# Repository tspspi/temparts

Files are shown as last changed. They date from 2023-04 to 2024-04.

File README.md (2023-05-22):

# Various parts for transmission electron microscopy

## Sampleholder template for the FEI TECNAI F20/G20

## Mirror sample tip for coherent photon measurement on the FEI TECNAI F20/G20

## Mirrors for coherent photon measurement on the FEI TECNAI F20/G20

## For simulation: Template of the Octagon of the FEI TECNAI F20/G20

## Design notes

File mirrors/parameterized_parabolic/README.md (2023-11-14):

# Parameterizable parabolic mirror

## Base mirror: ```parabolic_base```

This is a simple parameterizable parabolic mirror.

| | |
| --- | --- |
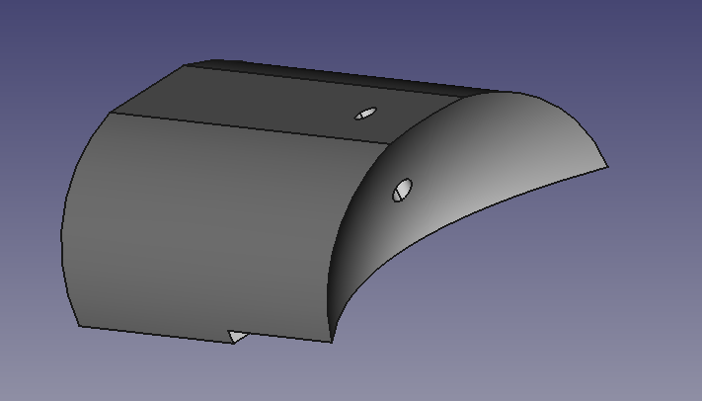
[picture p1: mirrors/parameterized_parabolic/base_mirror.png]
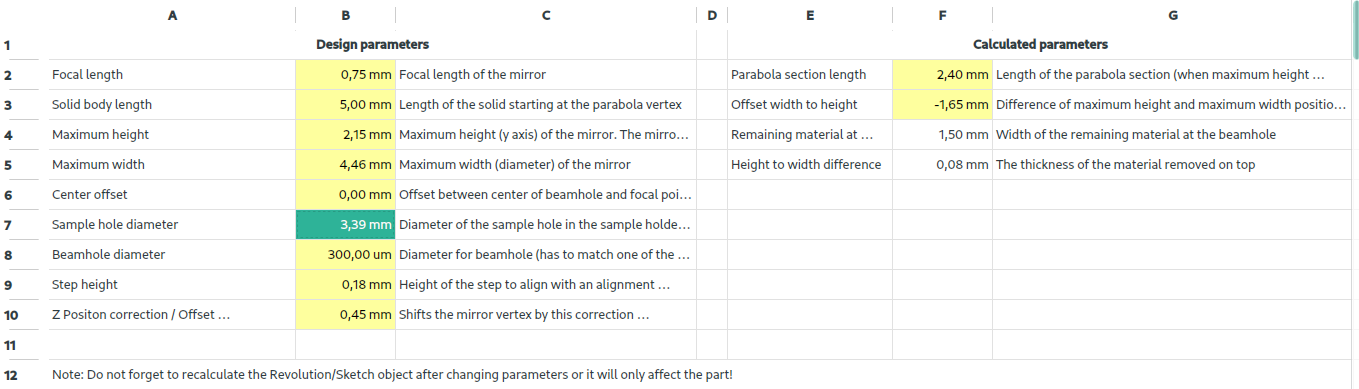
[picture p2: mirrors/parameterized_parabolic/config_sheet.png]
|  |  |

## Mirror with screw mount: ```parabolic_screwmount```

The same mirror model (using the same configuration) with a simple screw
mount

| | |
| --- | --- |
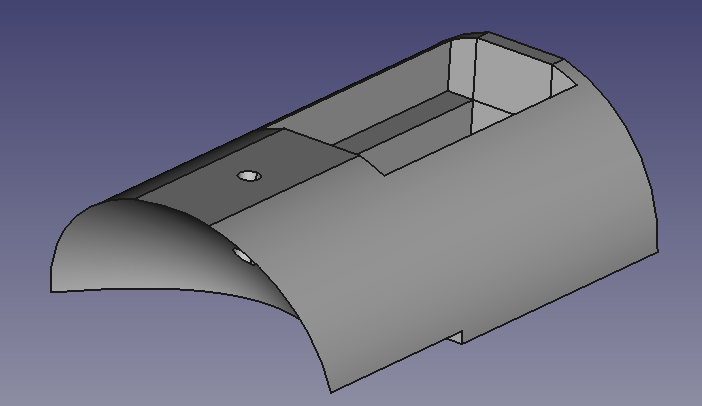
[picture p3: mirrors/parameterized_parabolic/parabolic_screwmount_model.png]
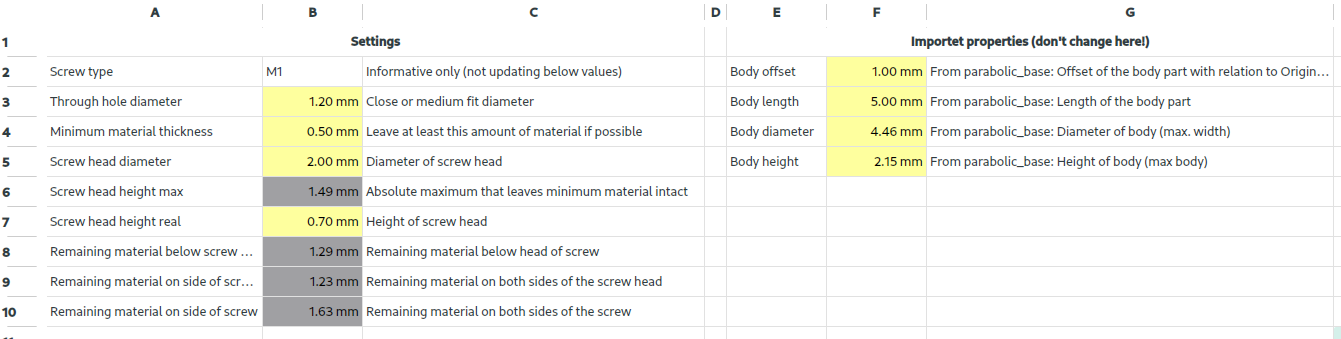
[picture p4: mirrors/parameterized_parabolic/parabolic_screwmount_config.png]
|  |  |

## Simulation with screw mount

There is a (currently incomplete - not including the sample holder) parameterized
simulation that pulls design parameters from the other models for the screw mounted
parabolic mirror in ```parabolic_simulation```

| | |
| --- | --- |
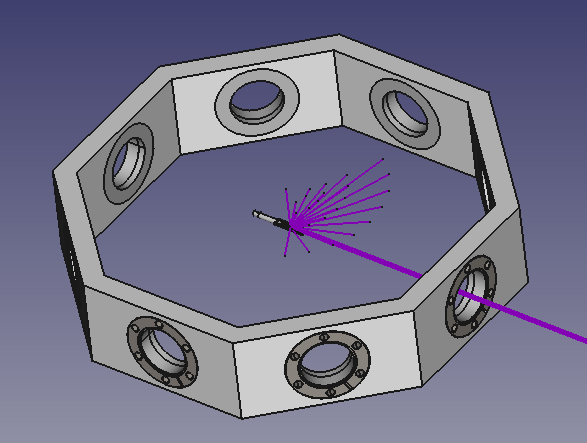
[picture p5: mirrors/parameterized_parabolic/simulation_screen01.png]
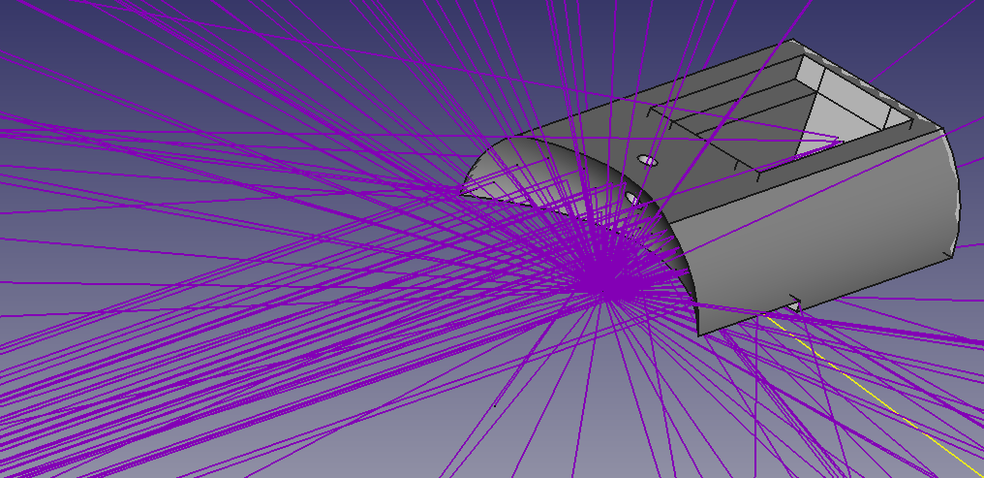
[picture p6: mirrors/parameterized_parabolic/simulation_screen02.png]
|  |  |
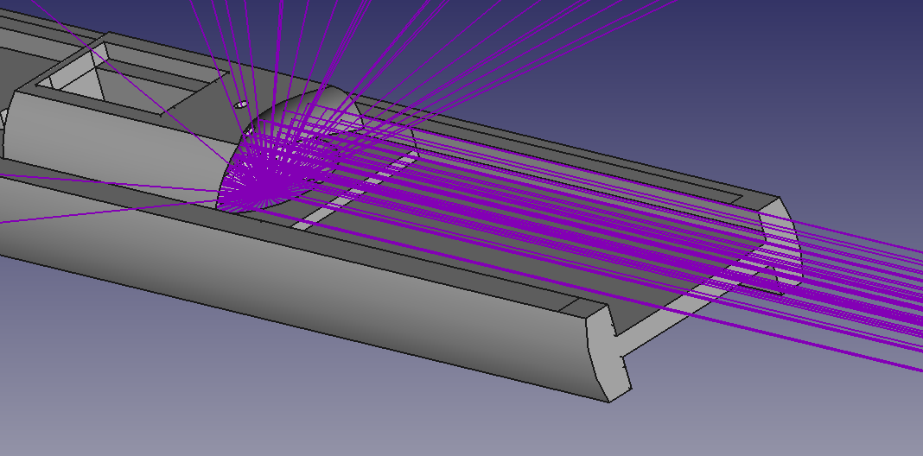
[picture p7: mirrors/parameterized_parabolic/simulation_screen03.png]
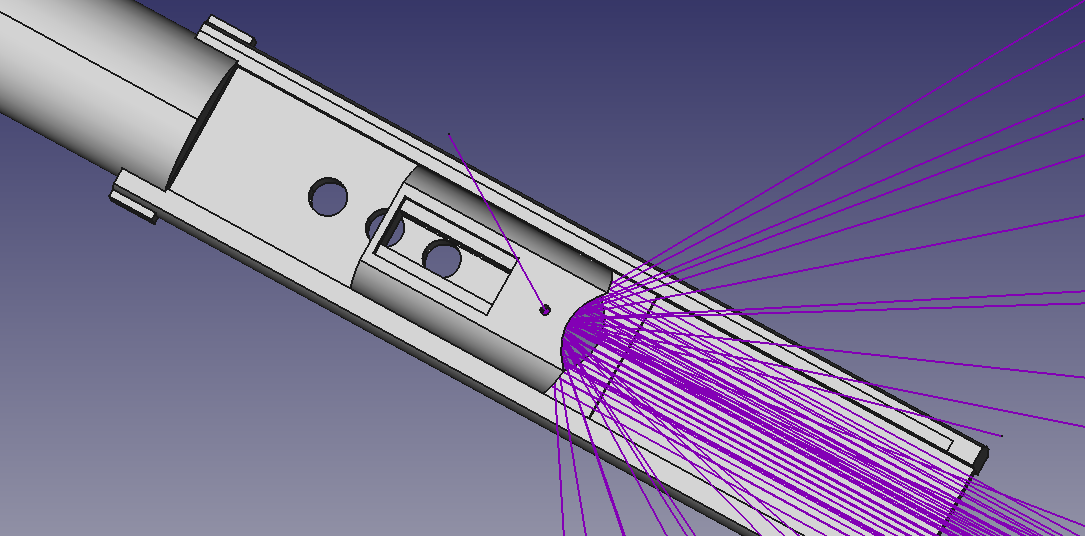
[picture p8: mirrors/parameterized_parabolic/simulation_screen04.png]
|  |  |

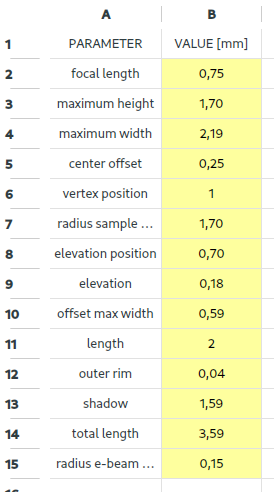
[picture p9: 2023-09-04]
mirrors/parabolic/tem_mirror_parabolic_designparameters.png

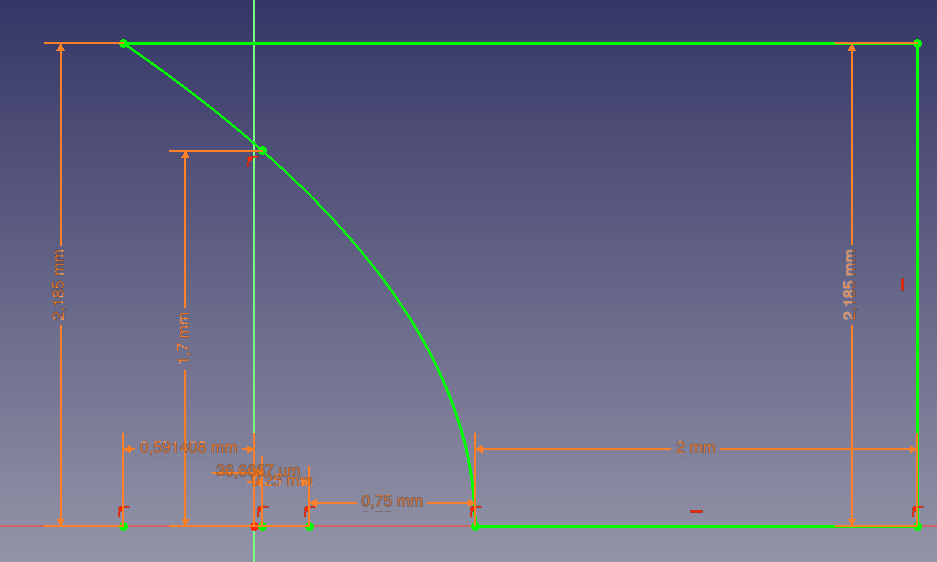
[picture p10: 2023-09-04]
mirrors/parabolic/tem_mirror_parabolic_design.png

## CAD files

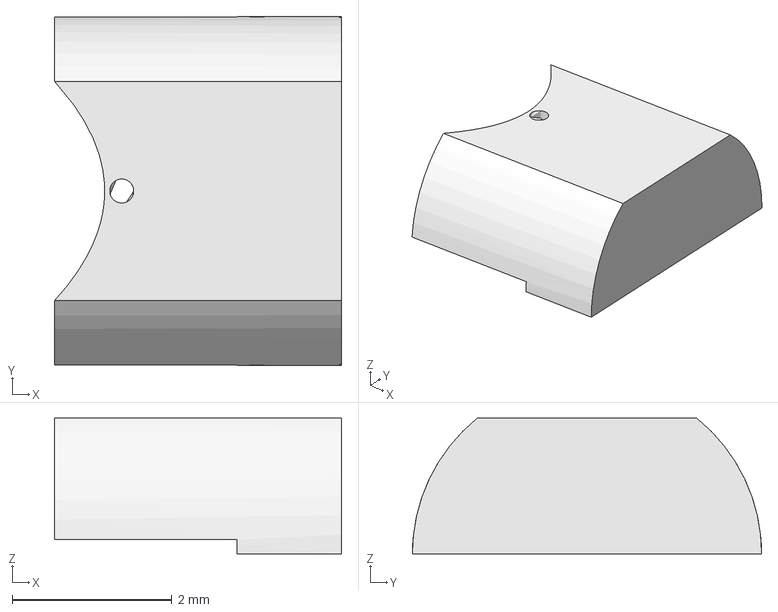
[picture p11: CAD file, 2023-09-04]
mirrors/parabolic/tem_mirror_parabolic.step
3.59 x 4.37 x 1.70 mm

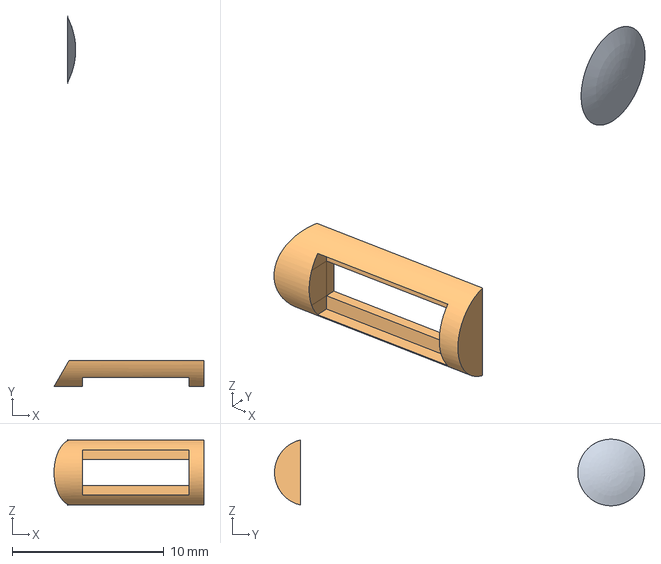
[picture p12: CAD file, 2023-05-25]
mirrors/tem_mirror_flat2_30deg.FCStd
9.89 x 24.4 x 4.40 mm

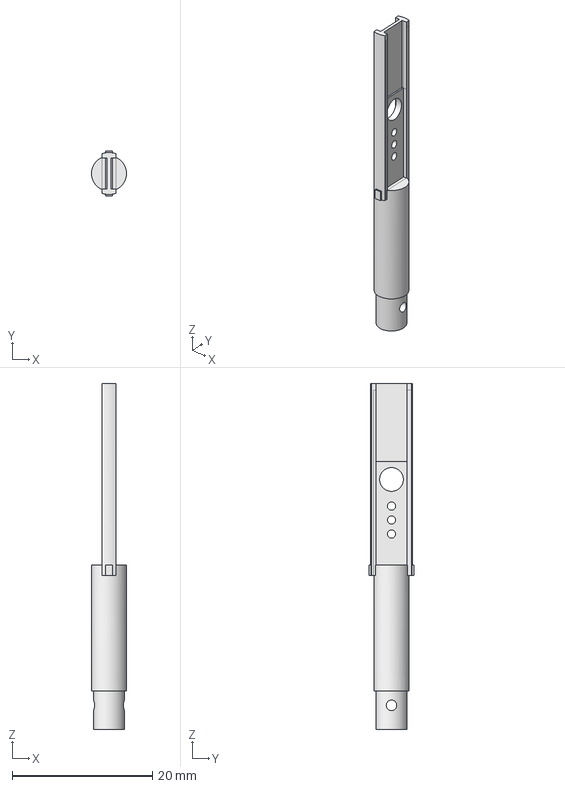
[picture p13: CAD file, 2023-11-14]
sampleholder/temholder2.FCStd
5.00 x 6.40 x 49.4 mm

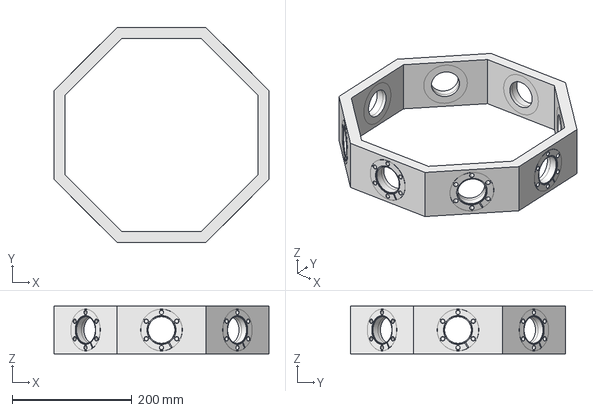
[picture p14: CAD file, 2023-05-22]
templates/tem_octagon.FCStd
358.9 x 358.9 x 80.0 mm

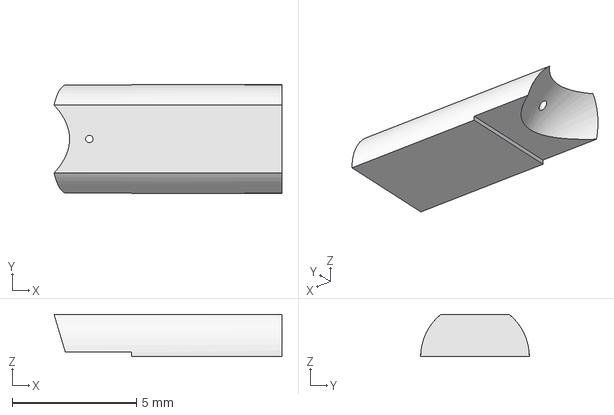
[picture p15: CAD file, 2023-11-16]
mirrors/parameterized_parabolic/parabolic_base.FCStd
9.17 x 4.37 x 1.70 mm

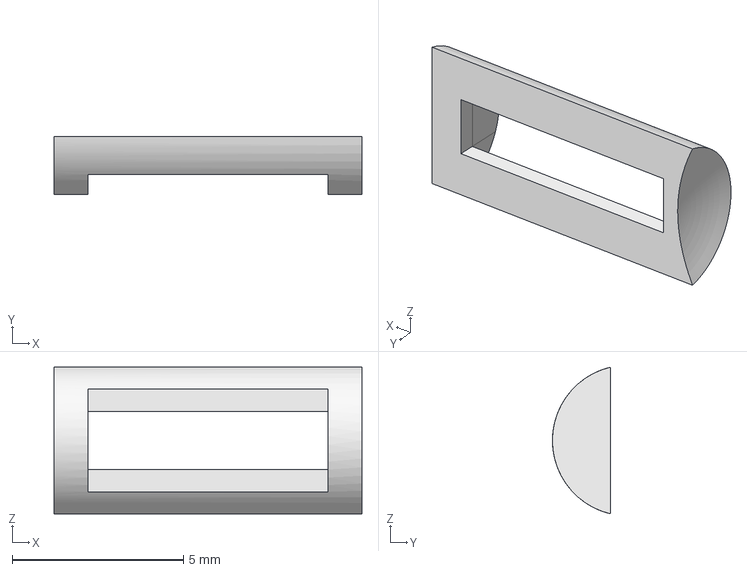
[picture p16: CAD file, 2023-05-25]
mirrors/tem_mirror_parabolic.fcstd
9.00 x 1.70 x 4.28 mm

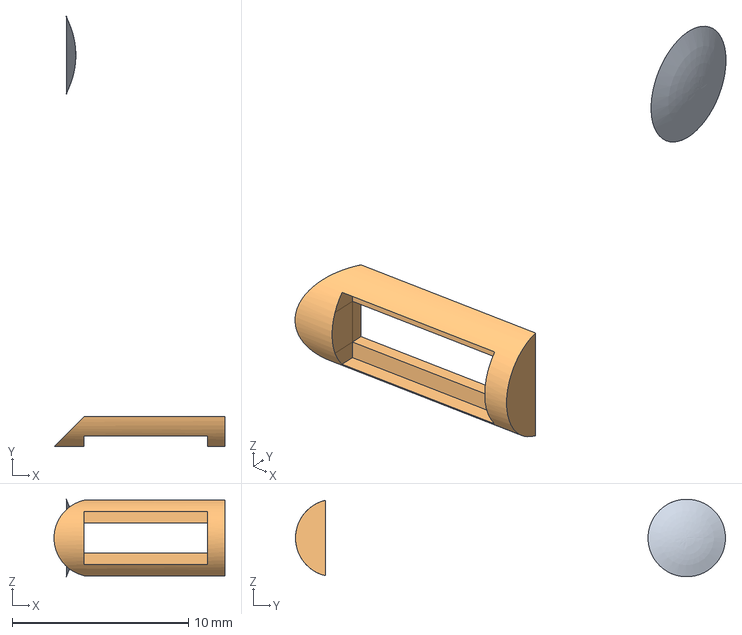
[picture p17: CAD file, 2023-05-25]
mirrors/tem_mirror_flat2.FCStd
9.70 x 24.4 x 4.40 mm

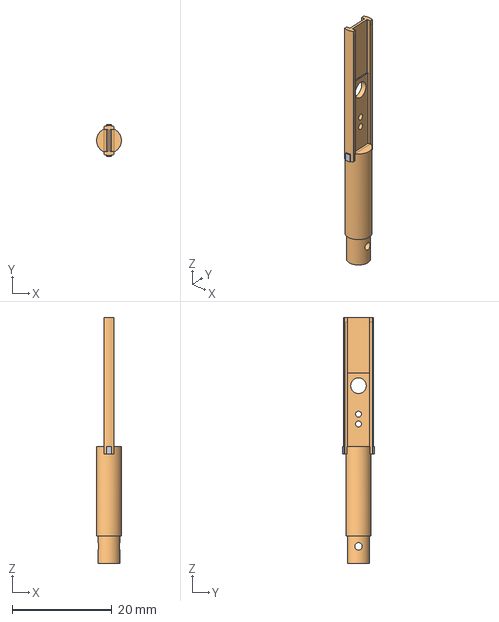
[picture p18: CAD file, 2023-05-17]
sampleholder/temholder_mirror_01.FCStd
5.00 x 6.40 x 49.4 mm
Würfel002

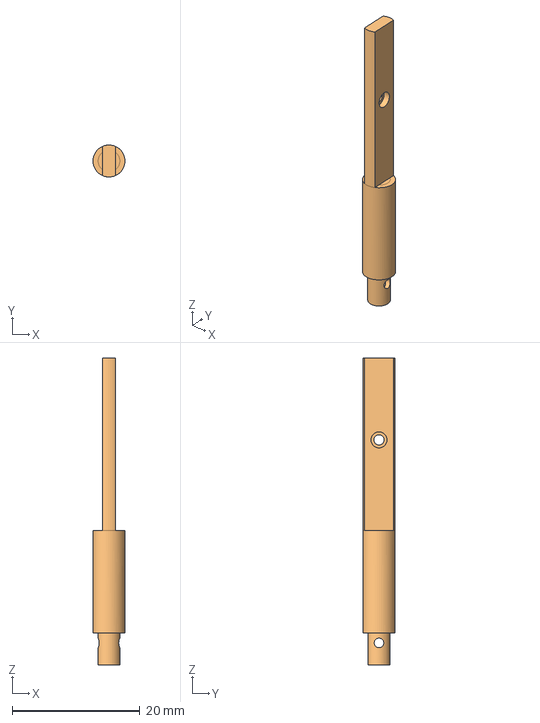
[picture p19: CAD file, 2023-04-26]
sampleholder/temholder.FCStd
5.00 x 5.00 x 48.0 mm
Fusion001 (Solid)

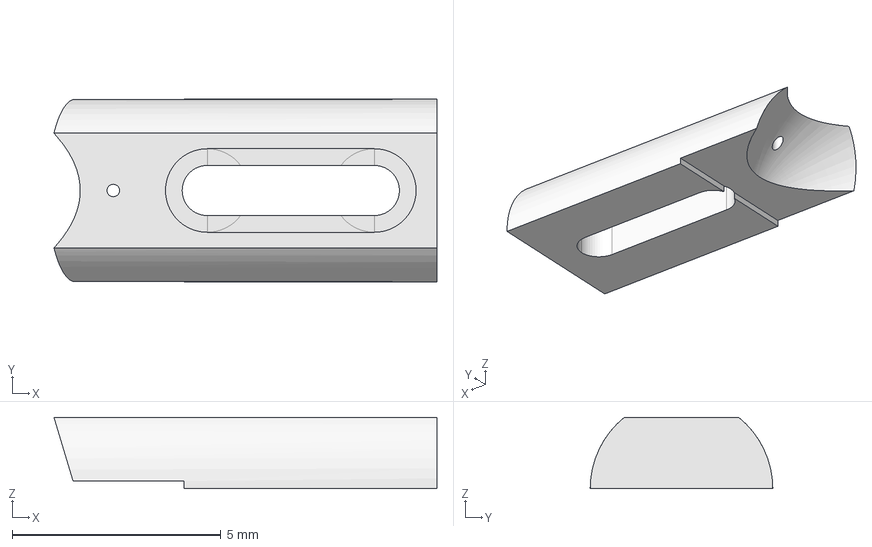
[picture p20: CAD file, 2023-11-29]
mirrors/parameterized_parabolic/manufacturedVariants/20231129_changedParabolicScrewmount.step
9.17 x 4.37 x 1.70 mm

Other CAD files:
sampleholder/temholder2_2.iges
mirrors/parameterized_parabolic/parabolic_simulation.FCStd
mirrors/parameterized_parabolic/parabolic_screwmount.FCStd
mirrors/parameterized_parabolic/manufacturedVariants/20231116_ParabolicScrewmount.step
mirrors/parabolic/tem_mirror_parabolic.FCStd
mirrors/parabolic/tem_mirror_parabolic.iges
mirrors/parameterized_parabolic/manufacturedVariants/20231116_ParabolicScrewmount.iges
mirrors/parameterized_parabolic/manufacturedVariants/20231129_changedParabolicScrewmount.iges
sampleholder/temholder2.iges

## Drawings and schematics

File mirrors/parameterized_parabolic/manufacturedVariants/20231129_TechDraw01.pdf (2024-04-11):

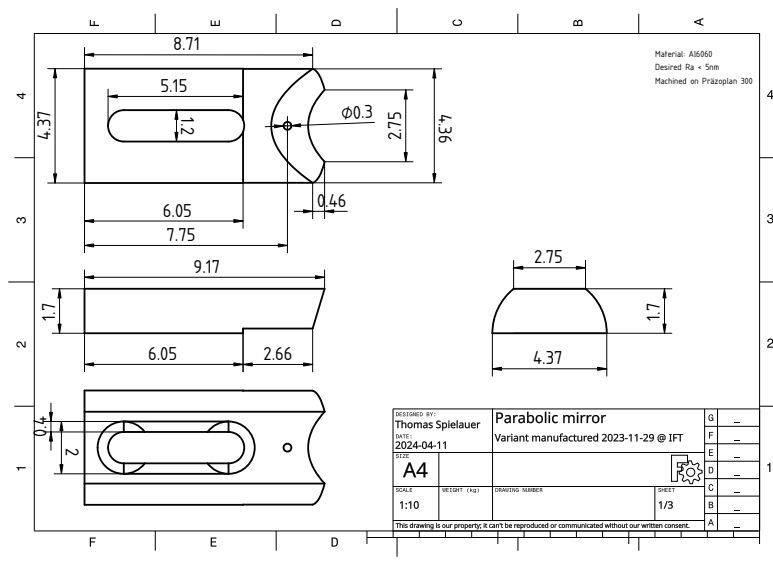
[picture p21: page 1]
Material: Al6060 Desired Ra < 5nm Machined on Präzoplan 300

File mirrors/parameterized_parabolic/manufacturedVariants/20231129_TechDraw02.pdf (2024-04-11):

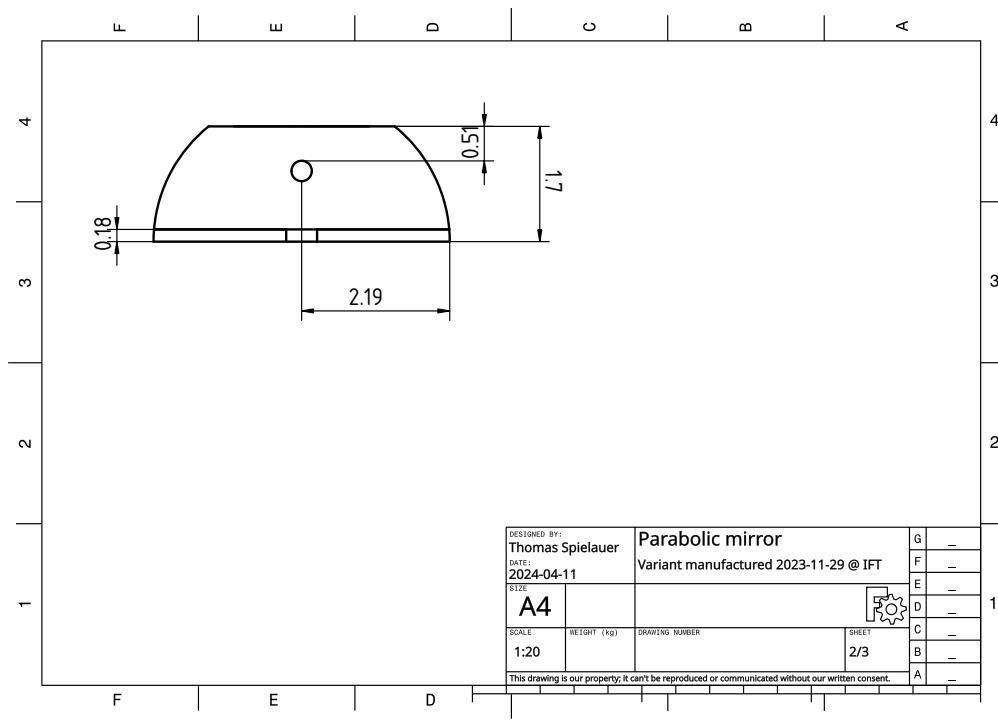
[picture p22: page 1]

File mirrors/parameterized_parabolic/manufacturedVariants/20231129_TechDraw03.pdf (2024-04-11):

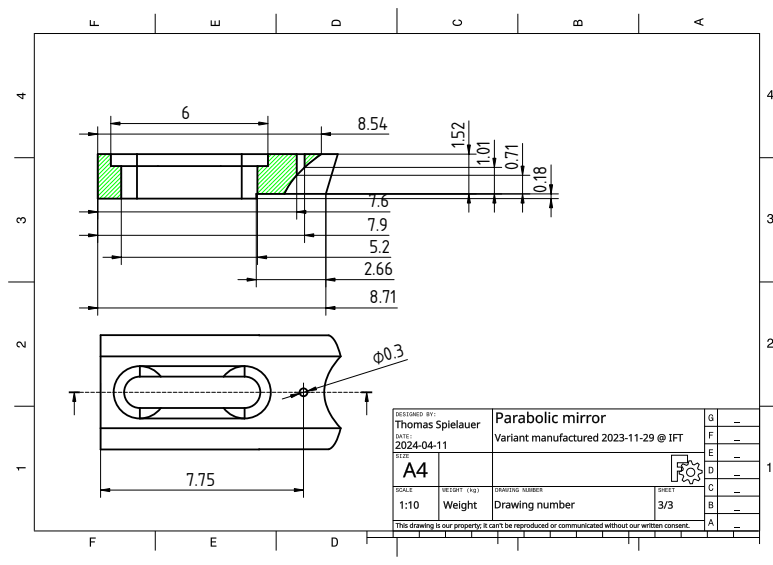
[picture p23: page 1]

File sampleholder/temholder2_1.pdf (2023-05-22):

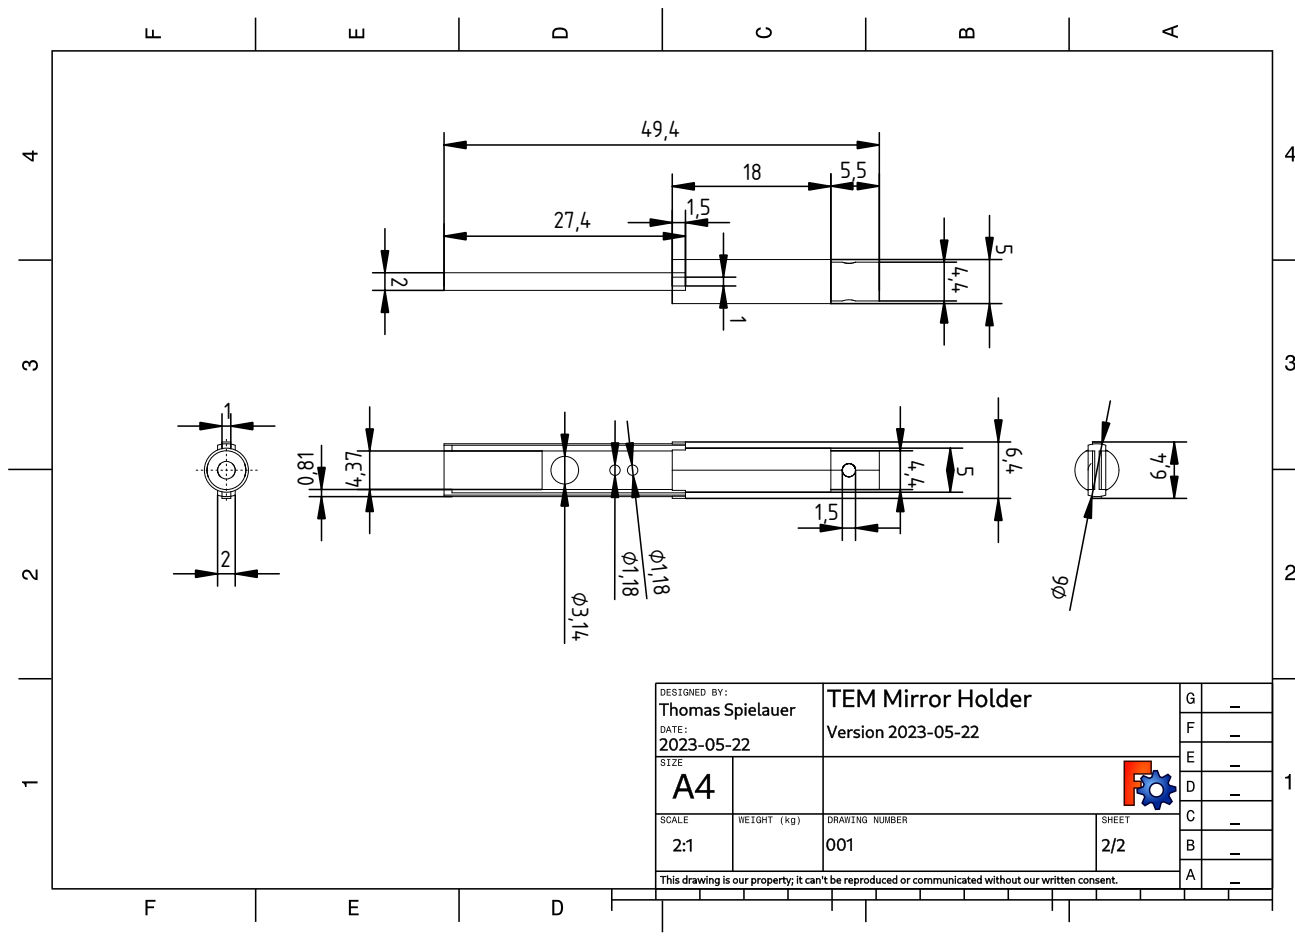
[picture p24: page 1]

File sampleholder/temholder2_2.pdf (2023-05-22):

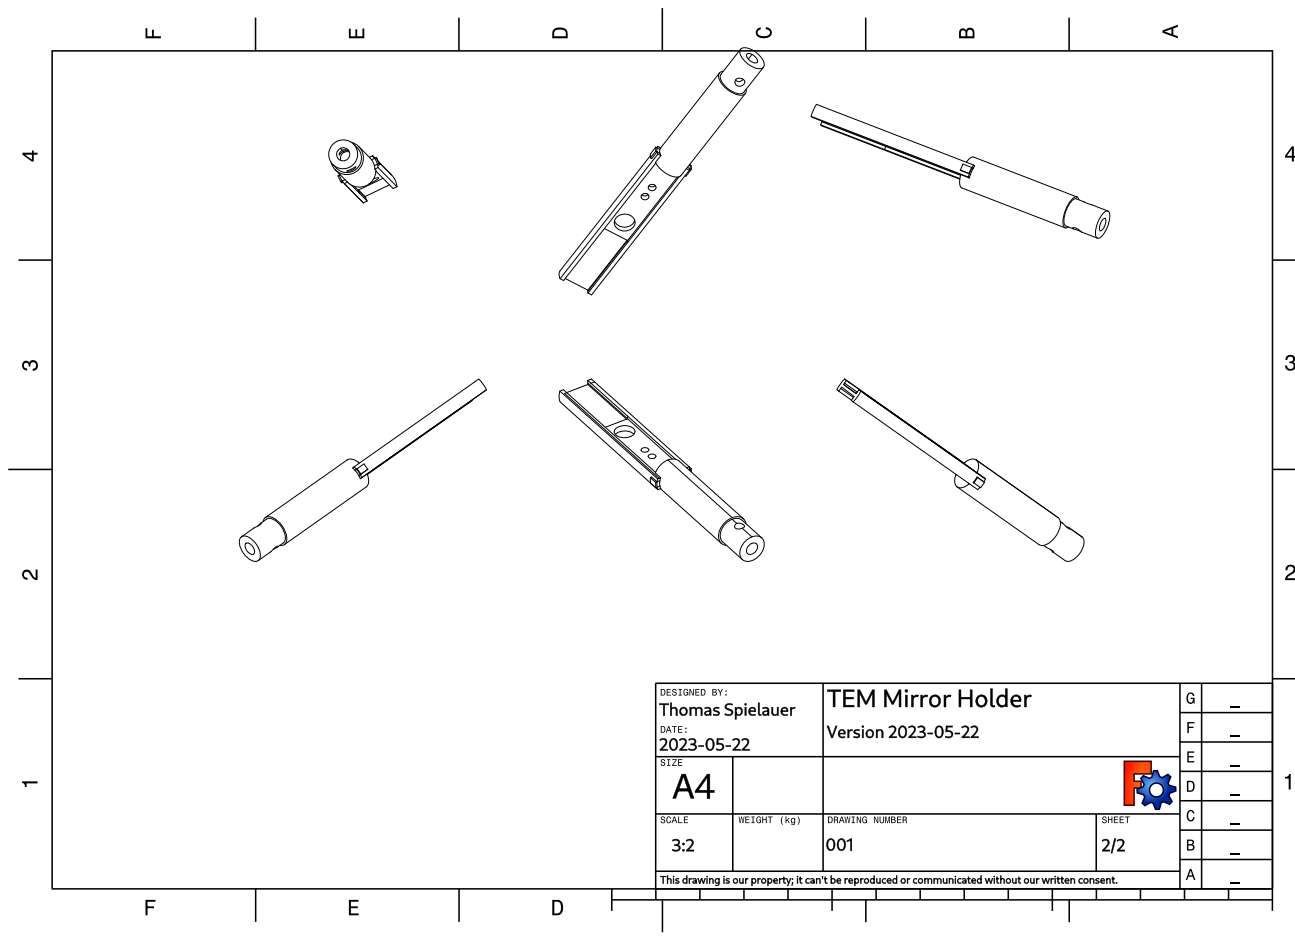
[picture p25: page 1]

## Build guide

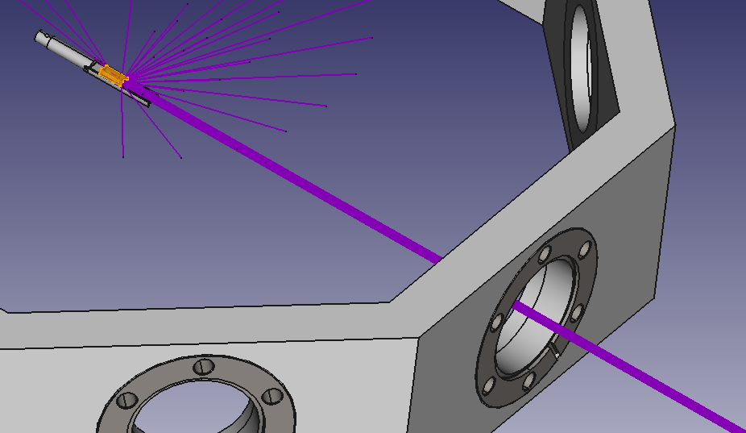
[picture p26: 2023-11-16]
mirrors/parameterized_parabolic/manufacturedVariants/20231116_ParabolicScrewmount_004.png

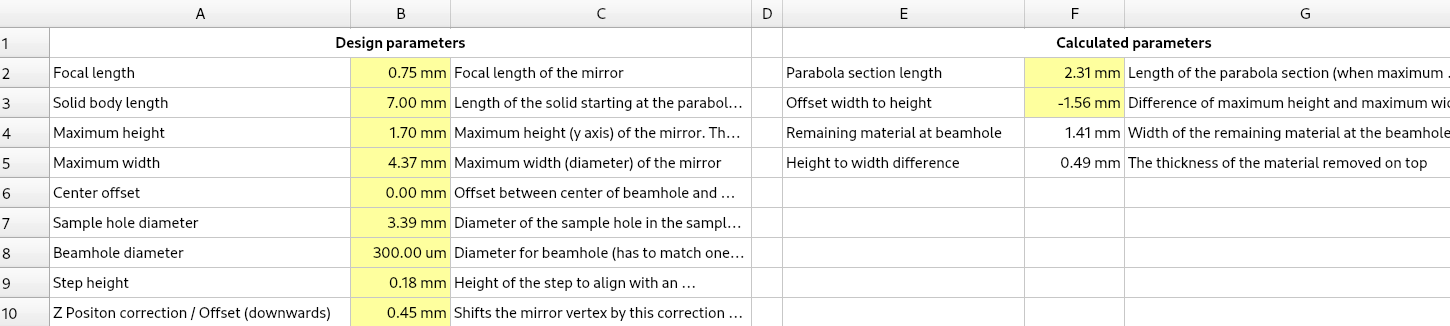
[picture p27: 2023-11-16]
mirrors/parameterized_parabolic/manufacturedVariants/20231116_ParabolicScrewmount_002.png

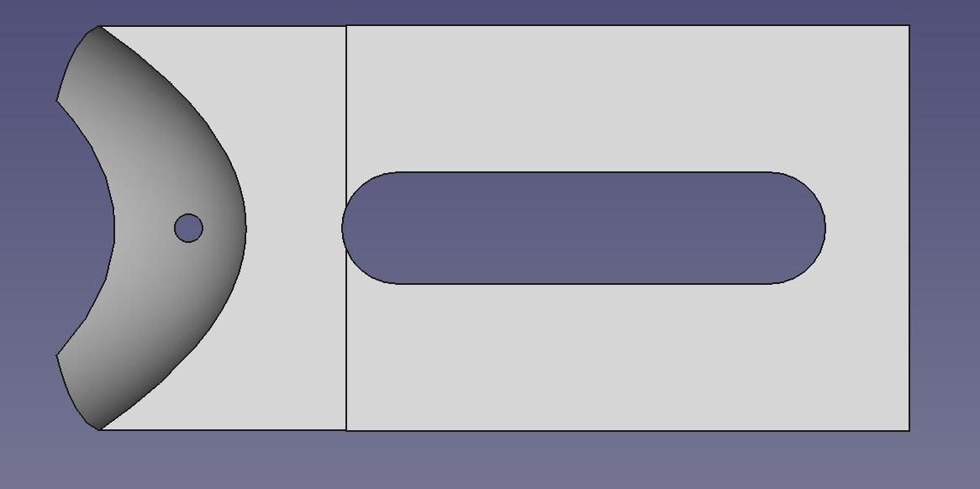
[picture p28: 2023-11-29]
mirrors/parameterized_parabolic/manufacturedVariants/20231129_changedParabolicScrewmount_001.png

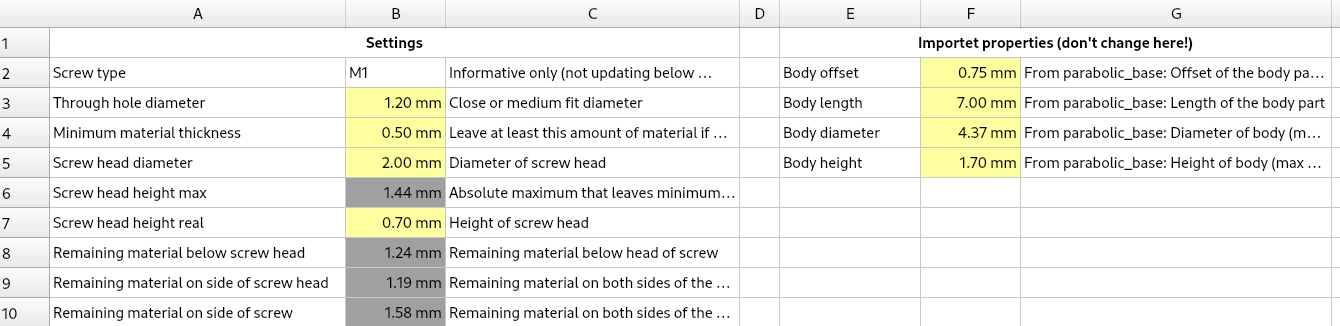
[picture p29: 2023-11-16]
mirrors/parameterized_parabolic/manufacturedVariants/20231116_ParabolicScrewmount_001.png

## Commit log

2023-04-26 Adding two TEM sampleholder templates
    [temholder.FCStd, temholder2.FCStd]
2023-05-17 Adding new TEM holder with grooved for mirror, 2 M1.6 threads for mirror mounting and MF4x0.2 retaining ring sample holder
    [temholder_mirror_01.FCStd]
2023-05-17 Adding parabolic mirror
    [tem_mirror_parabolic.fcstd]
2023-05-22 Added technical drawings
    [temholder2.FCStd, temholder2.iges]
2023-05-22 Template octagon for simulations
    [tem_octagon.FCStd]
2023-05-25 Parabolic mirror thicker, new flat mirror
    [tem_mirror_flat2.FCStd, tem_mirror_parabolic.fcstd]
2023-05-25 30 degree variant of flat mirror
    [tem_mirror_flat2_30deg.FCStd]
2023-05-25 Added IGES
    [temholder2_2.iges]
2023-09-04 Update parabolic mirror design, adding step
    [tem_mirror_parabolic.FCStd, tem_mirror_parabolic.fcstd, tem_mirror_parabolic.iges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]
2023-09-04 STEP format conversion
    [tem_mirror_parabolic.step]
2023-11-07 Adding parameterized parabolic mirror design (base mirror, no mounts)
    [parabolic_base.FCStd]
2023-11-07 Update with minor fixes and z offset option
    [parabolic_base.FCStd]
2023-11-07 Minor bugfix
    [parabolic_base.FCStd]
2023-11-07 Adding version with simple screw mount
    [parabolic_screwmount.FCStd]
2023-11-14 Fixed to model
    * Fixed length calculation in parabolic_base (parabola_section_length_uncut)
    * Fixed calculation of offset width to height (height_to_width_offset)
    * Fixed shifting of parabola with zpos_offset
    * Fixed outer radius limit when shifting parabola
    * Updated parabolic_screwmount to use the new volume limited model
    [parabolic_base.FCStd, parabolic_screwmount.FCStd]
2023-11-14 Set model parameters without beamhole shift
    [parabolic_base.FCStd, parabolic_screwmount.FCStd]
2023-11-14 Modified parameters for actual project
    [parabolic_base.FCStd, parabolic_screwmount.FCStd]
2023-11-14 Adding simple raytracing (not including holder)
    [parabolic_simulation.FCStd]
2023-11-14 Adding configurable offset along sampleholder axis
    [parabolic_simulation.FCStd]
2023-11-14 Adjust fixed mountholes to match current revision
    [temholder2.FCStd]
2023-11-14 Update simulation to include sample holder (at fixed position)
    [parabolic_simulation.FCStd]
2023-11-14 Adding fixed TEM holder to simulation
    [parabolic_simulation.FCStd]
2023-11-16 Increase length of mounting hole so one can keep always two screws inside
    [parabolic_base.FCStd, parabolic_screwmount.FCStd]
2023-11-16 Added data for manufactured variant
    [20231116_ParabolicScrewmount.iges, 20231116_ParabolicScrewmount.step]
2023-11-29 Minor modification to mounting hole
    The mounting hole now is a real long hole instead of a square pocket. First
    of course a square pocket cannot be manufactured exactly due to the mill form
    and second this will leave way more material in vicinity of the lower edge
    so the part won't be torn appart as easy while milling.
    [20231129_changedParabolicScrewmount.iges, 20231129_changedParabolicScrewmount.step, parabolic_screwmount.FCStd]
